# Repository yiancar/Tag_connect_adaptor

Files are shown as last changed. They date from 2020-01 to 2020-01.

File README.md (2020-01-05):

# TAG-Connect Adapter
 A simple routing PCB to connect a TAG-Connect cable to different programmers.

 This is designed to use a [TC2030-MCP-NL](http://www.tag-connect.com/TC2030-MCP-NL) cable and route it to:
 * Atmel ISP 10pin programmers such as [USBASP](https://hobbycomponents.com/usb-interface/841-usbasp-avr-programmer-adaptor)
 * [ST-LINK V2 clone programmer](https://www.amazon.co.uk/Youmile-Emulator-Downloader-Programmer-Programming/dp/B07QBLNDPM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). Please note that SWIM is at pin 5 and has been [modded](https://lujji.github.io/blog/stlink-clone-trace/) to be SWO.

 The BYPASS DIP switches can be used to disconnect a connection from the TAG cable to the programmer outputs. This way, the INPUT header can route the TAG cable to any device.

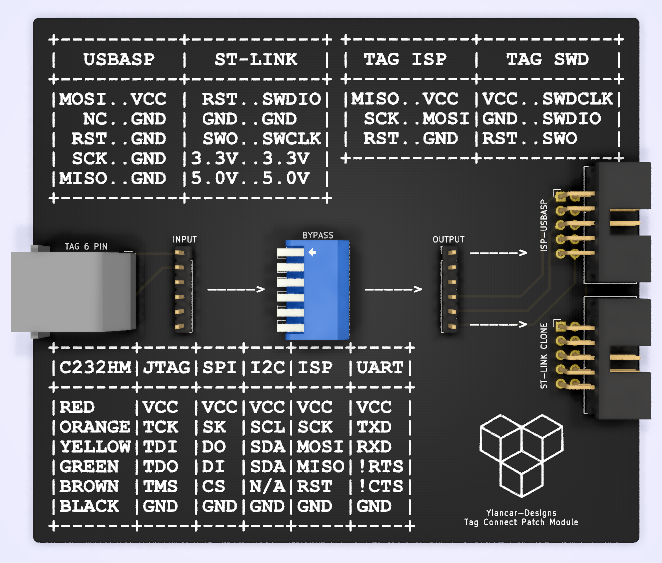
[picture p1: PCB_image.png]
PCB Image


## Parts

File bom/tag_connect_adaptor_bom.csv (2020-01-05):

Reference | Quantity | Value | Footprint | Source Link
J1 | 1 | INPUT | Connector_PinHeader_2.54mm:PinHeader_1x06_P2.54mm_Vertical | https://lcsc.com/product-detail/Pin-Header-Female-Header_BOOMELE-Boom-Precision-Elec-C37208_C37208.html
J2 | 1 | OUTPUT | Connector_PinHeader_2.54mm:PinHeader_1x06_P2.54mm_Vertical | https://lcsc.com/product-detail/Pin-Header-Female-Header_BOOMELE-Boom-Precision-Elec-C37208_C37208.html
J3 | 1 | ISP-AVR | Connector_IDC:IDC-Header_2x05_P2.54mm_Horizontal | https://lcsc.com/product-detail/IDC-Connectors_BOOMELE-Boom-Precision-Elec-C9140_C9140.html
J4 | 1 | ST-LINK CLONE | Connector_IDC:IDC-Header_2x05_P2.54mm_Horizontal | https://lcsc.com/product-detail/IDC-Connectors_BOOMELE-Boom-Precision-Elec-C9140_C9140.html
J5 | 1 | RJ25 | Connector_RJ:RJ12_Amphenol_54601 | https://lcsc.com/product-detail/Ethernet-Connectors-Modular-Connectors-RJ45-RJ11_TE-Connectivity_5555163-1_TE-Connectivity-5555163-1_C305982.html
SW1 | 1 | BYPASS | Button_Switch_THT:SW_DIP_SPSTx06_Piano_10.8x16.8mm_W7.62mm_P2.54mm | https://lcsc.com/product-detail/DIP-Switches_XKB-Enterprise-DPL-06RP_C319067.html

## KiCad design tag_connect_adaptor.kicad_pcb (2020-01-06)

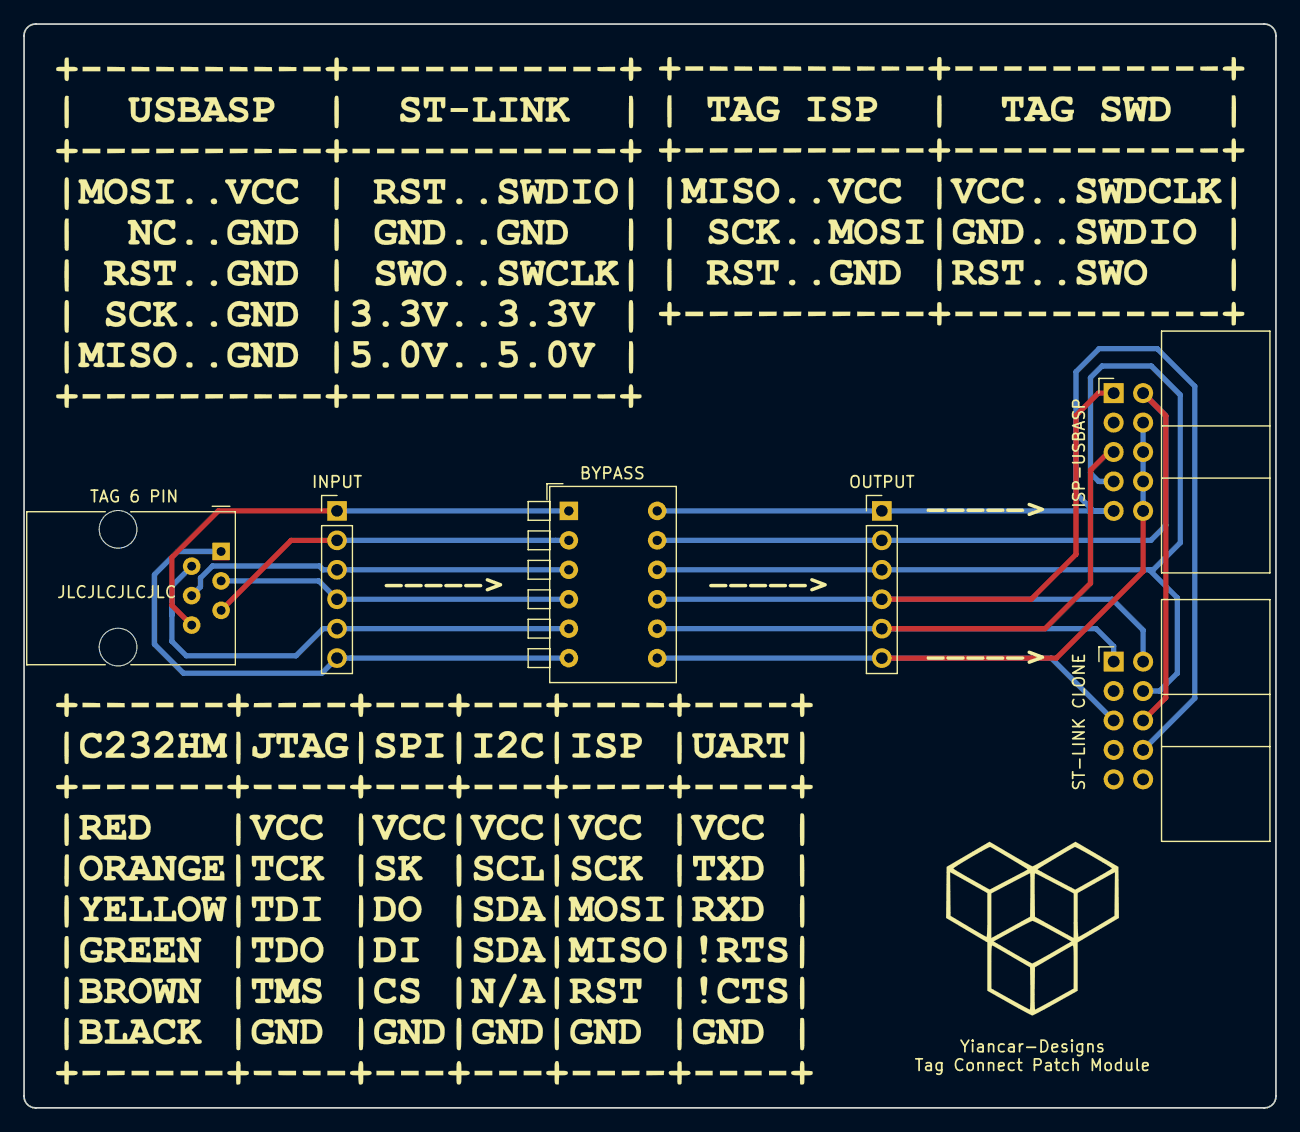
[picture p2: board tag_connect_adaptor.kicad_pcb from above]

Board: 2 copper layers, 108.0 x 93.5 mm, 6 parts (0 on the bottom side), 12 nets.

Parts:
J1: INPUT; PinHeader_1x06_P2.54mm_Vertical
J2: OUTPUT; PinHeader_1x06_P2.54mm_Vertical
J3: ISP-USBASP; IDC-Header_2x05_P2.54mm_Horizontal
J4: ST-LINK CLONE; IDC-Header_2x05_P2.54mm_Horizontal
J5: TAG 6 PIN; RJ12_Amphenol_54601
SW1: BYPASS; SW_DIP_SPSTx06_Piano_10.8x16.8mm_W7.62mm_P2.54mm

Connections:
/TAG1: J1.1, J5.6, SW1.1
/TAG2: J1.2, J5.5, SW1.2
/TAG3: J1.3, J5.4, SW1.3
/TAG4: J1.4, J5.3, SW1.4
/TAG5: J1.5, J5.2, SW1.5
/TAG6: J1.6, J5.1, SW1.6
/TAG_SW1: J2.1, J3.9, J4.8, SW1.12
/TAG_SW2: J2.2, J3.2, J4.6, SW1.11
/TAG_SW3: J2.3, J3.7, J4.4, SW1.10
/TAG_SW4: J2.4, J3.1, J4.2, SW1.9
/TAG_SW5: J2.5, J3.5, J4.1, SW1.8
/TAG_SW6: J2.6, J3.4, J3.6, J3.8, J3.10, J4.5, SW1.7

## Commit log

2020-01-05 Generate gerbers
    [tag_connect_adaptor-B_Cu.gbl, tag_connect_adaptor-B_Mask.gbs, tag_connect_adaptor-B_Paste.gbp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]
2020-01-06 Numpering update
    [tag_connect_adaptor-B_Cu.gbl, tag_connect_adaptor-B_Mask.gbs, tag_connect_adaptor-B_Paste.gbp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]
